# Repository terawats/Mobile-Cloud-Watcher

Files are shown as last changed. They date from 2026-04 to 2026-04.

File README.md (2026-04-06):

# DIY Mobile Cloud Watcher with RF433MHz Remote Alarm
CloudWatcherSet
A DIY Mobile Cloud Watcher with an RF433MHz remote alarm designed specifically for astrophotographers.

## Background
Thermal radiation from the ground is reflected back to Earth by clouds. By using an IR sky temperature sensor, we can estimate cloud cover based on temperature fluctuations. This project uses this concept to trigger an alarm before the rain actually arrives, giving you time to protect your equipment.

## Bill of Materials
Below are the parts required for this project:
| Items | Pictures | Details |
|---|---|-----|
| 1 | GY-906_MLX90614 | IR Temperature sensor |
| 2 | ESP8266_with_18650_Battery-icon | ESP8266 with 18650 battery charger |
| 3 | RF433MHzDoorBell-icon | RF 433MHz remote door bell (3.3V battery only)|
| 4 | switch | Switch for power On/Off |
| 5 | 18650_Battery | 18650 Battery|
| 6 | CloudWatcher_inside-icon | IR Temperature sensor |

## Hardware Modification: ESP8266 Analog Input
The original ESP8266 A0 analog input is designed for a 1.0V maximum. To monitor the battery voltage (up to 5.0V), we need to modify the voltage divider.

### Change the original voltage divider resistor from 100kΩ to 56kΩ as shown in the schematic below.
A0-mod

## Battery Monitoring
Connect the battery voltage to the A0 input to enable monitoring. You can check the real-time battery voltage and percentage via the web interface.
ESP8266_A0_mod

## Wiring Diagrams
Schemetic diagram

## Assembly Reference
### Wiring on A-side
CloudWatcher_wiringA

### Wiring on B-side
CloudWatcher_wiringB

### Battery Charging Port
The 18650 battery can be charged via the micro USB port. The charging status is indicated by the LED.

Green : Charging
CloudWatcher_chargerPort

## Configuration & Web Interface
1. Place the Cloud Watcher in an open area with a clear view of the sky.

2. Turn on the power and connect your device to the following WiFi:

      SSID     : "Cloud-Watcher-Panel"

      Password : "12345678"

3. Open your web browser and navigate to: http://192.168.0.1

### Monitoring & Setup
The web interface displays the current sky temperature and battery level. A fully charged 2000mAh battery typically lasts for 2-3 nights of continuous monitoring.

  * Sky Temperature Chart: After 3-5 minutes, the chart will display the temperature history.

  * Alarm Threshold: Set your temperature limit approximately 1-2 degrees higher than the baseline shown in the history chart to trigger the alarm.
web_monitor_ticked

### Alarm Triggering
When cloud cover is detected, the unit sends an RF433MHz signal to the doorbell receiver.

  * Testing: You can test the alarm by placing your hand over the sensor for 2-3 seconds.

  * Safety: Cloud detection typically occurs well before rain starts, providing a crucial early warning to save your expensive astrophotography gear.
web_monitor

Let enjoy and clear sky.

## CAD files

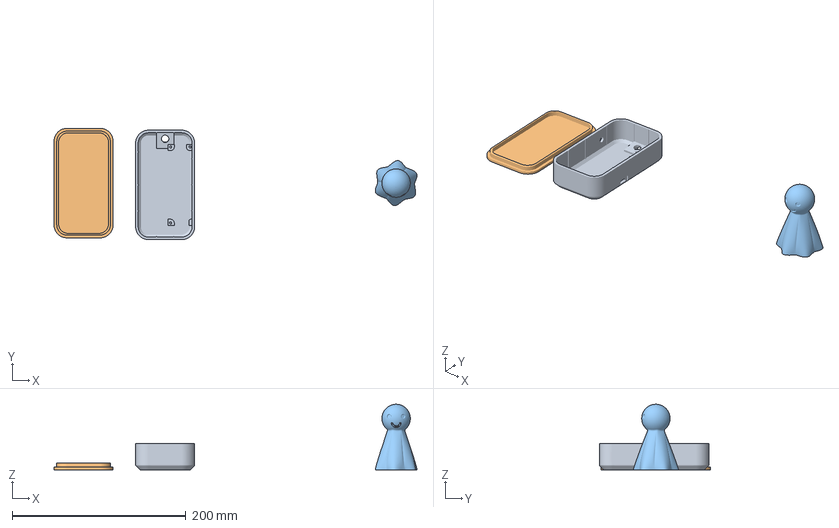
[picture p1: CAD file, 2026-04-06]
3D_Print_STL/CloudWatcherAlarm.3mf
417.6 x 128.1 x 75.4 mm
CloudWatcherAlarm_Box.stl
CloudWatcherAlarm_Cover.stl
Rain Doll.stl

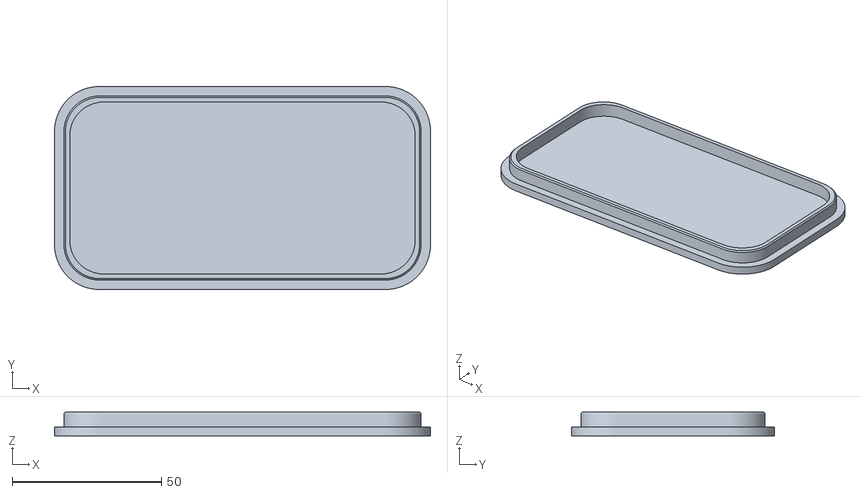
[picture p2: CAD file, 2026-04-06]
3D_Print_STL/CloudWatcherAlarm_Cover.stl
126.0 x 68.0 x 8.00

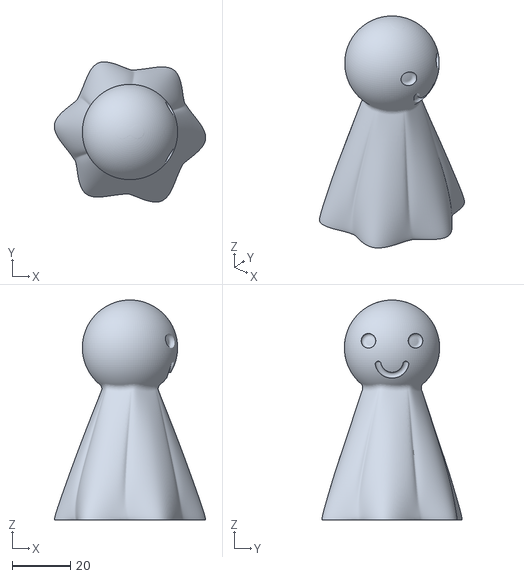
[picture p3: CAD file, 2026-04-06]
3D_Print_STL/Rain Doll.stl
51.9 x 48.1 x 75.4

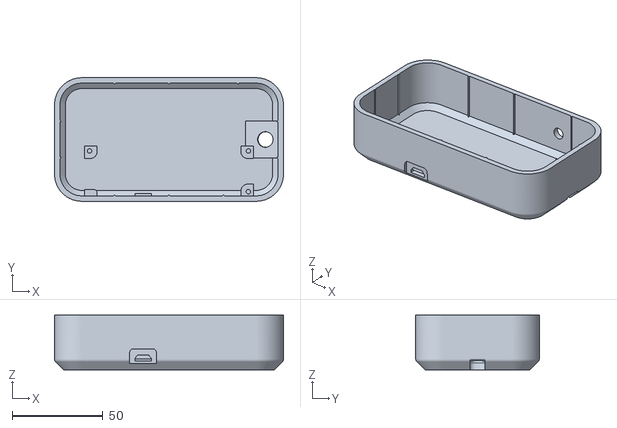
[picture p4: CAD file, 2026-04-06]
3D_Print_STL/CloudWatcherAlarm_Box.stl
126.0 x 68.0 x 30.0

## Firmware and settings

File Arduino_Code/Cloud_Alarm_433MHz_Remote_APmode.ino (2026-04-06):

#include <ESP8266WiFi.h>
#include <ESP8266WebServer.h>
#include <Wire.h>
#include <Adafruit_MLX90614.h>
#include <EEPROM.h>
#include "index.h"

// WiFi AP credentials
const char* ssid = "Cloud-Watcher-Panel";
const char* password = "12345678";

// Static IP address setup
IPAddress local_IP(192, 168, 0, 1); 
IPAddress gateway(192, 168, 0, 1);
IPAddress subnet(255, 255, 255, 0);
IPAddress primaryDNS(192,168, 0, 1);

ESP8266WebServer server(80);

// Create an instance of the MLX90614 sensor
Adafruit_MLX90614 mlx = Adafruit_MLX90614();

// IO Pin
int LEDPin = D0; 
int RF433_Relay_pin = D5; 

// Battery monitoring
const int BATTERY_PIN = A0;
const float VOLTAGE_DIVIDER_RATIO = 5.0; // 1/5 voltage divider
const float MAX_BATTERY_VOLTAGE = 4.2; // Li-ion max voltage

// SkyTemperature data storage (720 readings for 12 hours at 1 minute intervals)
const int MAX_READINGS = 720;
float SkyTemperatures[MAX_READINGS];
unsigned long timestamps[MAX_READINGS];
int currentIndex = 0;
bool arrayFull = false;

// SkyTemperature limit settings
float SkyTemperatureLimit = 30.0;  // Default SkyTemperature limit
float sky_temperature = 15;
int sky_unsafe_status = 0;

const int EEPROM_TEMP_LIMIT_ADDR = 0;  // EEPROM address for SkyTemperature limit
int LED_toggle = 0;

// Timing variables
unsigned long previousSensorReadTime;
unsigned long previousChartIndexTime;
unsigned long sky_previous_unsafe_time;
unsigned long currentmillis;
const unsigned long READING_INTERVAL = 1000; // 1 sec in milliseconds
const unsigned long intervalUnsafeTime = 10000; // 10 sec to reset alarm for re-triger

void takeSkyTemperatureReading() {
    float temp;  
    float objectTemperature;
    float ambientTemperature;

    currentmillis = millis();

    temp = mlx.readObjectTempC();
    temp = mlx.readObjectTempC();
    if(isnan(temp)){
      Serial.println("Failed to read SkyTemperature !!!");
    }else{
      objectTemperature = temp;
    }
    ambientTemperature = mlx.readAmbientTempC();
    sky_temperature = objectTemperature - ( (33.0/100)*(ambientTemperature) + (8.0/100)*pow((exp(100.0/1000*ambientTemperature)) , (100.0/100)) ) + 10;

    // Shift data index every 60 sec.
    if(currentmillis - previousChartIndexTime > 60000){ // 60,000 millisec
      previousChartIndexTime = currentmillis ;
      if(currentIndex < MAX_READINGS - 1){
          currentIndex++;
      }
      if (currentIndex == MAX_READINGS - 1) {
        arrayFull = true;
        //shift SkyTemperature array
        for (int i = 0; i < MAX_READINGS - 2 ; i++) {
          SkyTemperatures[i] = SkyTemperatures[i + 1];
          timestamps[i] = timestamps[i + 1];
        }
        SkyTemperatures[MAX_READINGS - 1] = 0;
        timestamps[MAX_READINGS - 1] = currentmillis;
      }
    }

    if(sky_temperature > SkyTemperatures[currentIndex]){
        SkyTemperatures[currentIndex] = sky_temperature;
        timestamps[currentIndex] = currentmillis;
    }
    Serial.print("SkyTemperature reading ");
    Serial.print(currentIndex);
    Serial.print(": ");
    Serial.print(sky_temperature);
    Serial.print("°C, ");
    Serial.print("Ambient Temperature : ");
    Serial.print(ambientTemperature);
    Serial.print("°C, ");
    Serial.print("sky_unsafe_status : ");
    Serial.print(sky_unsafe_status);
    Serial.print(", Battery % : ");
    Serial.println(getBatteryPercentage());
}

void handleRoot() {
  server.send(200, "text/html", html);
}

void handleData() {
  String json = "{";
  json += "\"SkyTemperatures\":[";
  
  int count = arrayFull ? MAX_READINGS : currentIndex;
  int startIdx = arrayFull ? currentIndex : 0;
  
  for (int i = 0; i <= currentIndex; i++) {
    if (i > 0) json += ",";
    json += String(SkyTemperatures[i], 2);
  }
  
  json += "],\"timestamps\":[";
  
  for (int i = 0; i <= currentIndex; i++) {
    if (i > 0) json += ",";
    json += String(timestamps[i]);
  }

  json += "],\"battery\":[";
  json += String(getBatteryPercentage());

  json += "]}";
  
  server.send(200, "application/json", json);
}

void handleCurrent() {
  float temp = 25.1; //mlx.readObjectTempC();
  String json = "{\"SkyTemperature\":" + String(temp, 2) + "}";
  server.send(200, "application/json", json);
}

void handleGetLimit() {
  String json = "{\"limit\":" + String(SkyTemperatureLimit, 1) + "}";
  server.send(200, "application/json", json);
}

void handleSetLimit() {
  if (server.hasArg("limit")) {
    float newLimit = server.arg("limit").toFloat();
    if (newLimit >= 0 && newLimit <= 100) {  // Reasonable SkyTemperature range
      SkyTemperatureLimit = newLimit;
      saveSkyTemperatureLimitToEEPROM();
      Serial.print("SkyTemperature limit updated to: ");
      Serial.print(SkyTemperatureLimit);
      Serial.println("°C");
      server.send(200, "application/json", "{\"status\":\"success\",\"limit\":" + String(SkyTemperatureLimit, 1) + "}");
    } else {
      server.send(400, "application/json", "{\"status\":\"error\",\"message\":\"Invalid limit range (0-100)\"}");
    }
  } else {
    server.send(400, "application/json", "{\"status\":\"error\",\"message\":\"Missing limit parameter\"}");
  }
}

void handleGetBattery() {
  String json = "{\"battery\":" + String(getBatteryPercentage(), 1) + "}";
  server.send(200, "application/json", json);
}

void loadSkyTemperatureLimitFromEEPROM() {
  // Read SkyTemperature limit from EEPROM
  EEPROM.begin(sizeof(SkyTemperatureLimit)*2);
  EEPROM.get(EEPROM_TEMP_LIMIT_ADDR, SkyTemperatureLimit);
  EEPROM.end();
  
  // Check if EEPROM value is valid (not NaN or out of reasonable range)
  if (isnan(SkyTemperatureLimit) || SkyTemperatureLimit < 0 || SkyTemperatureLimit > 100) {
    SkyTemperatureLimit = 30.0;  // Default value
    saveSkyTemperatureLimitToEEPROM();  // Save default to EEPROM
  }
}

void saveSkyTemperatureLimitToEEPROM() {
  EEPROM.begin(sizeof(SkyTemperatureLimit)*2);
  EEPROM.put(EEPROM_TEMP_LIMIT_ADDR, SkyTemperatureLimit);
  EEPROM.commit();
  EEPROM.end();
}

void Send_RF433MHz_alarm()
{
  digitalWrite(RF433_Relay_pin, LOW); 
  delay(500);
  digitalWrite(RF433_Relay_pin, HIGH); 
}

float getBatteryPercentage() {
  int rawValue = analogRead(BATTERY_PIN);
  float voltage = (rawValue / 1024.0) * VOLTAGE_DIVIDER_RATIO;
  float percentage = ((voltage - 3.0) / (MAX_BATTERY_VOLTAGE - 3.0)) * 100.0;
  return constrain(percentage, 0.0, 100.0);
}

void LowBatteryCheck(){
  if(getBatteryPercentage() < 5.0){
    Serial.println("Battery critical level --> Shutdown in 10 seconds");
    for(int i=0;i<33;i++){
      digitalWrite(LEDPin, HIGH); 
      delay(150);
      digitalWrite(LEDPin, LOW); 
      delay(150);
    }
    ESP.deepSleep(0);
  }
}

void setup() {
  // Initial IO pin
  pinMode(LEDPin, OUTPUT);
  pinMode(RF433_Relay_pin, OUTPUT);
  pinMode(BATTERY_PIN, INPUT);
  digitalWrite(LEDPin, HIGH); 
  digitalWrite(RF433_Relay_pin, HIGH); 

  Serial.begin(115200);
  delay(1000);
  
  // Low battery check
  LowBatteryCheck();

  // Initialize I2C and MLX90614
  if (!mlx.begin()) {
    Serial.println("Error connecting to MLX sensor. Check wiring.");
    while (1);
  }
  
  // Initialize EEPROM
  //********** Un-comment for 1st use EEPROM *******************
  // saveSkyTemperatureLimitToEEPROM()
  //************************************************************

  // Load SkyTemperature limit from EEPROM
  loadSkyTemperatureLimitFromEEPROM();
  
  Serial.println("MLX90614 initialized successfully");
  Serial.print("SkyTemperature limit loaded: ");
  Serial.print(SkyTemperatureLimit);
  Serial.println("°C");
  
  // Initialize SkyTemperature array
  for (int i = 0; i < MAX_READINGS; i++) {
    SkyTemperatures[i] = 0.0;
    timestamps[i] = 0;
  }
  
  // Configure the soft AP with custom IP settings
  if (!WiFi.softAPConfig(local_IP, gateway, subnet)) {
    Serial.println("AP Config Failed");
  }

  // Setup WiFi AP
  WiFi.softAP(ssid, password);
  Serial.println();
  Serial.print("Access Point created: ");
  Serial.println(ssid);
  Serial.print("IP address: ");
  Serial.println(WiFi.softAPIP());
  
  // Setup web server routes
  server.on("/", handleRoot);
  server.on("/data", handleData);
  server.on("/current", handleCurrent);
  server.on("/battery", handleGetBattery);
  server.on("/setlimit", HTTP_POST, handleSetLimit);
  server.on("/getlimit", handleGetLimit);
  
  server.begin();
  Serial.println("HTTP server started");
  
  // Take initial reading
  currentmillis = millis();
  previousSensorReadTime = currentmillis;
  previousChartIndexTime = currentmillis;
  sky_previous_unsafe_time = currentmillis;
  takeSkyTemperatureReading();
}

void loop() {
  server.handleClient();
  
  // Take SkyTemperature reading every xx sec
  currentmillis = millis();
  if (currentmillis - previousSensorReadTime >= READING_INTERVAL) {
    if(LED_toggle == 1){
      digitalWrite(LEDPin, HIGH);
      LED_toggle = 0;
    } else {
      digitalWrite(LEDPin, LOW);
      LED_toggle = 1;
    }
    takeSkyTemperatureReading();
    previousSensorReadTime = currentmillis;
  }
  

  // cheeck for cloud, sky temperature over limit
  if(sky_temperature >= SkyTemperatureLimit){
    // Triger for remote alarm
    if(sky_unsafe_status == 0 ){
      sky_unsafe_status = 1; 
      Serial.println("Alarm !!!: Sky temperature over limit");
      Serial.print("Sky temperature: ");
      Serial.print(sky_temperature);
      Serial.print(", limit: ");
      Serial.println(SkyTemperatureLimit);
      Send_RF433MHz_alarm();
      sky_previous_unsafe_time = currentmillis;
    }else{
      if(sky_unsafe_status == 1 && (currentmillis - sky_previous_unsafe_time >= intervalUnsafeTime)){
        sky_unsafe_status = 0;
        Serial.println("Sky unsafe status are reseted by timmer");      
      }
    }
  }else{
    if(sky_unsafe_status == 1 && (currentmillis - sky_previous_unsafe_time >= intervalUnsafeTime)){
      sky_unsafe_status = 0;
      Serial.println("Sky unsafe status are cleared");
    }
  }

  LowBatteryCheck();
  delay(100);
}

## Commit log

2026-04-06 Arduino code for ESP8266
    Mobile cloud watcher with alarm
2026-04-06 3D Print for Box case
    3D Print for Box case
    [CloudWatcherAlarm.3mf, CloudWatcherAlarm_Box.stl, CloudWatcherAlarm_Cover.stl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]
